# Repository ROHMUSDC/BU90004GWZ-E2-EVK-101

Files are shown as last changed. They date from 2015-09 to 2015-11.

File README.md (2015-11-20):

# BU90004GWZ-E2-EVK-101 Design Resource Repository
* Hardware Design Files and Documentation for the ROHM BU90004GWZ-E2-EVK-101 EVK

----
### Description: 
* BU90004GWZ is a high efficiency 6MHz synchronous step-down switching regulator with ultra low current PFM mode.
* This DCDC Converter can provide up to 1.0A load current from an input voltage range between 3.0V to 5.5V
* optimized for battery powered portable applications
* Includes a mode control pin that allows the user to select between Forced PWM(Pulse Width Modulation) mode, PFM(Pulse Frequency Modulation) mode, or PWM/PFM Auto Change mode utilized power save operation at light load current

----
### Repository Contents
* Application Note Folder: Contains Draft Version of EVK Application Note
* Design Files: Contains Board, Gerber, Schematic, and BOM information for this EVK Board
* Measurement Reports Folder: Contains measurement testing information completed for these EVK Boards

----
### Where to Purchase?
* http://www.rohm.com/web/global/distribution/-/dinventory/BU90004GWZ-E2/sample/0

----
### DISCLAIMER
This Technical Data is protected under copyright laws.

ROHM hereby grants you a nonexclusive, nontransferable license to use this Technical Data 
as long as you abide by the terms and conditions of this DISCLAIMER. 

However, you are not authorized to sell, loan, rent, lease, redistribute or license this Technical Data, 
in whole or in part, or in modified form, to anyone.

You may modify this Technical Data to suit your specific applications, 
but the rights to derivative works and said modifications shall belong to ROHM. 

You may make copies of this Technical Data as necessary for internal use only within your company.

In any case, the latest datasheet is considered the final design guideline and represents 
the only actual performance specifications.

ROHM shall not be responsible for ensuring proper application on all computer systems.
This Technical Data is provided AS IS. ROHM makes no guarantees, either implicitly or explicitly, 
regarding its usability, functionality, accuracy, merchantability, or fitness for a specific purpose.

In addition, you shall take full responsibility for the use of any information acquired from this Technical Data. 

ROHM does not assume warranty of any kind arising from the use of this Technical Data. ACCORDINGLY, 
IN NO EVENT SHALL ROHM BE RESPONSIBLE, WHETHER THROUGH CONTRACT OR TORT LIABILITY, 
FOR ANY DAMAGES (INCLUDING BUT NOT LIMITED TO LOST PROFITS OR OTHER INCIDENTAL, CONSEQUENTAL, 
OR PUNITIVE DAMAGES) ARISING OUT OF OR IN CONNECTION WITH THE USE OR APPLICATION OF THIS Technical Data.

Furthermore, this Technical Data is subject to change without notice.

Unless otherwise expressly provided herein, ROHM does not convey any license under patent rights 
or any other intellectual property rights (including those of third parties).

ROHM is not obligated to provide maintenance or support for the Technical Data.

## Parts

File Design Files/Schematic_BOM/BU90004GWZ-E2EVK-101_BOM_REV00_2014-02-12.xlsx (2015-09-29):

TITLE & REVISION HISTORY Revised: Wednesday, February 12, 2014
xxxxx Revision: 00
Bill Of Materials February 12,2014 14:28:24 | Page1
Item | Quantity | Reference | Part | PCB Footprint | DESCRIPTION | MFG1 | MFG1_PART# | DISTR1 | DISTR1_PART# | Provided by ROHM | ROHM Comment
1 | 2 | C1,C2 | 4.7uF | C0603 | CAP CER 4.7UF 6.3V 10% X5R 0603 | Murata | GRM188R60J475KE19D | DIGIKEY | 490-3297-1-ND | Y
2 | 1 | C3 | 0.1uF | C0603 | CAP CER 0.1UF 25V 10% X7R 0603 | Murata | GRM188R71E104KA01D | DIGIKEY | 490-1524-1-ND | Y
3 | 1 | D1 | P4SMA6.8A | DO-214AC | DIODE TVS 400W 6.8V UNI 5% SMD | Littelfuse Inc | P4SMA6.8A | DIGIKEY | F5656CT-ND | N
4 | 2 | J1,J2 | 87224-3 | HDR_THVT_1X3_100 | CONN HEADER VERT .100 3POS 15AU | TE Connectivity | 87224-3 | DIGIKEY | A26545-ND | N
5 | 1 | L1 | 1.0uH | SMT_2P5X2P0_FIT | INDUCTOR POWER 1.0UH 2.3A SMD | TDK | MLP2520K1R0ST0S1 | DIGIKEY | 445-15739-1-ND | Y
6 | 2 | TP1,TP3 | TP_TH_63MIL_RED | TP_TH | TEST POINT PC MULTI PURPOSE RED | Keystone Electronics | 5010 | DIGIKEY | 5010K-ND | N
7 | 2 | TP2,TP4 | TP_TH_63MIL_BLK | TP_TH | TEST POINT PC MULTI PURPOSE BLK | Keystone Electronics | 5011 | DIGIKEY | 5011K-ND | N
8 | 1 | U1 | BU90004GWZ | UCSP35L1 | IC REG BUCK SYNC 1.8V 1A 6WLCSP | ROHM | BU90004GWZ-E2 | DIGIKEY | BU90004GWZ-E2TR-ND | Y
9 | 2 |  |  |  | Shunt jumper for header J1, J2 (item #4), CONN SHUNT 2POS GOLD W/HANDLE | TE Connectivity | 881545-1 | DIGIKEY | 881545-1-ND | N

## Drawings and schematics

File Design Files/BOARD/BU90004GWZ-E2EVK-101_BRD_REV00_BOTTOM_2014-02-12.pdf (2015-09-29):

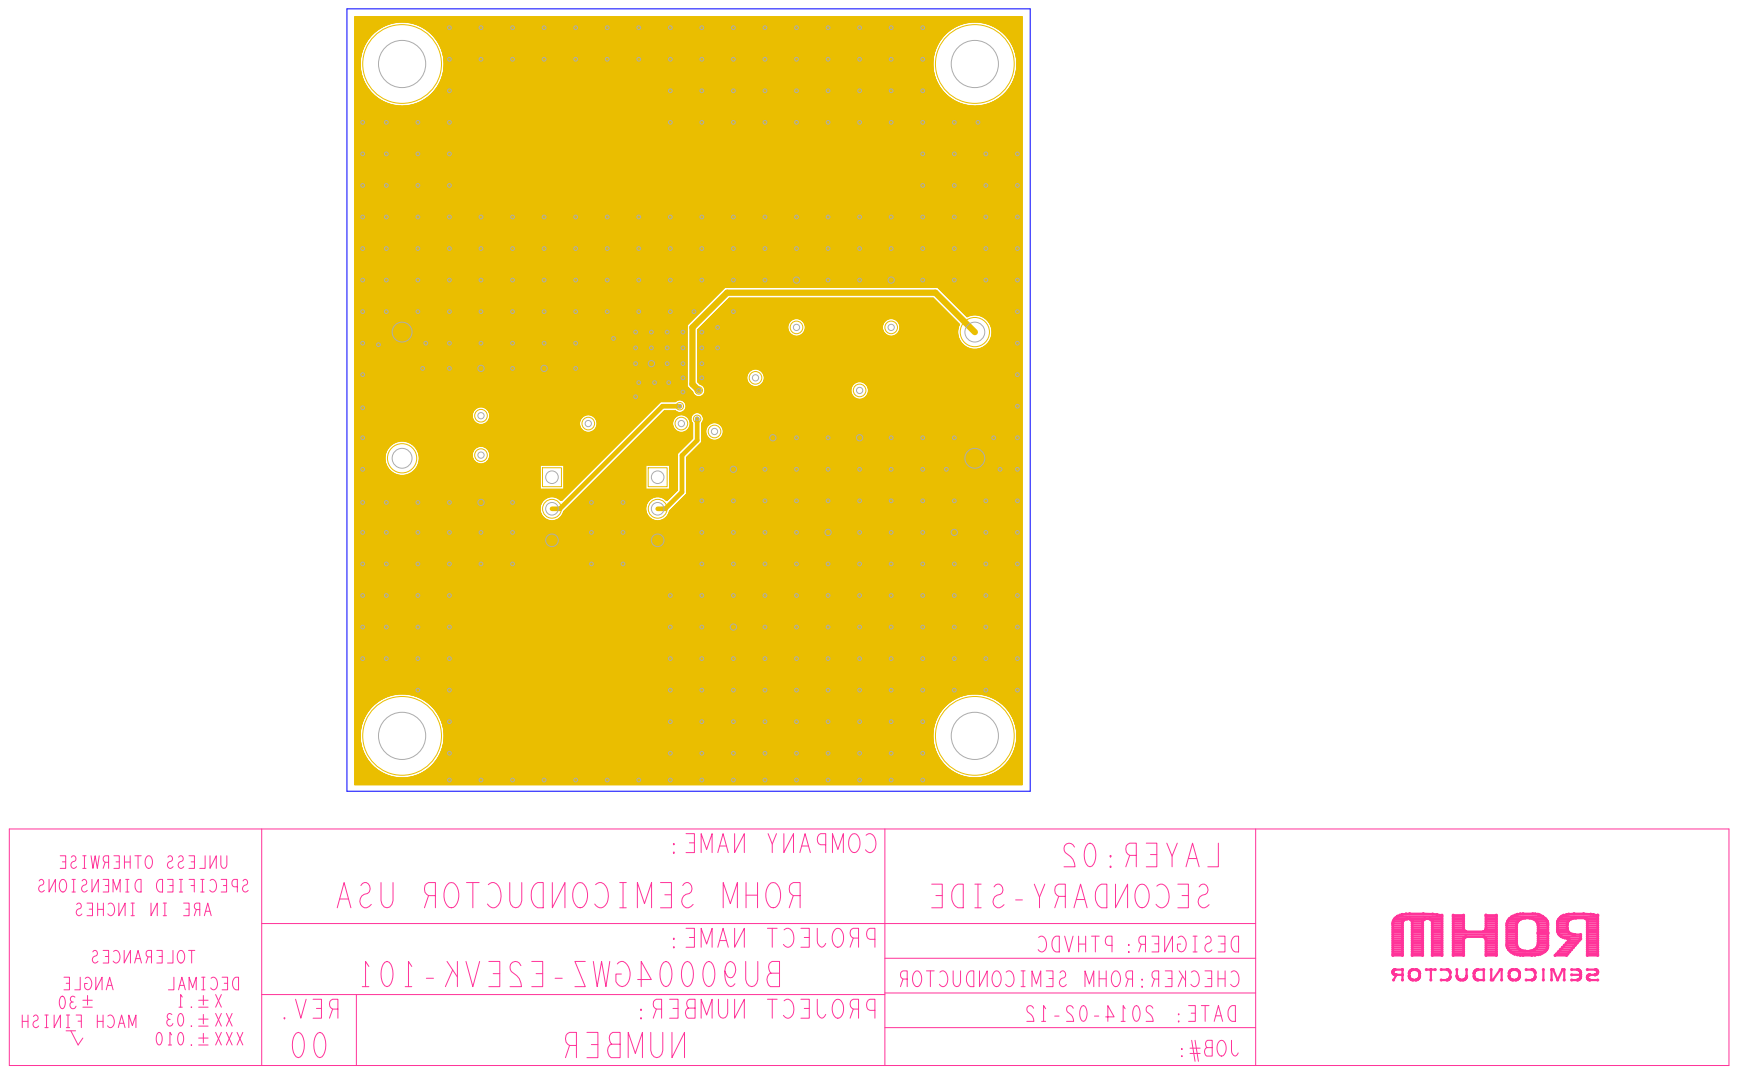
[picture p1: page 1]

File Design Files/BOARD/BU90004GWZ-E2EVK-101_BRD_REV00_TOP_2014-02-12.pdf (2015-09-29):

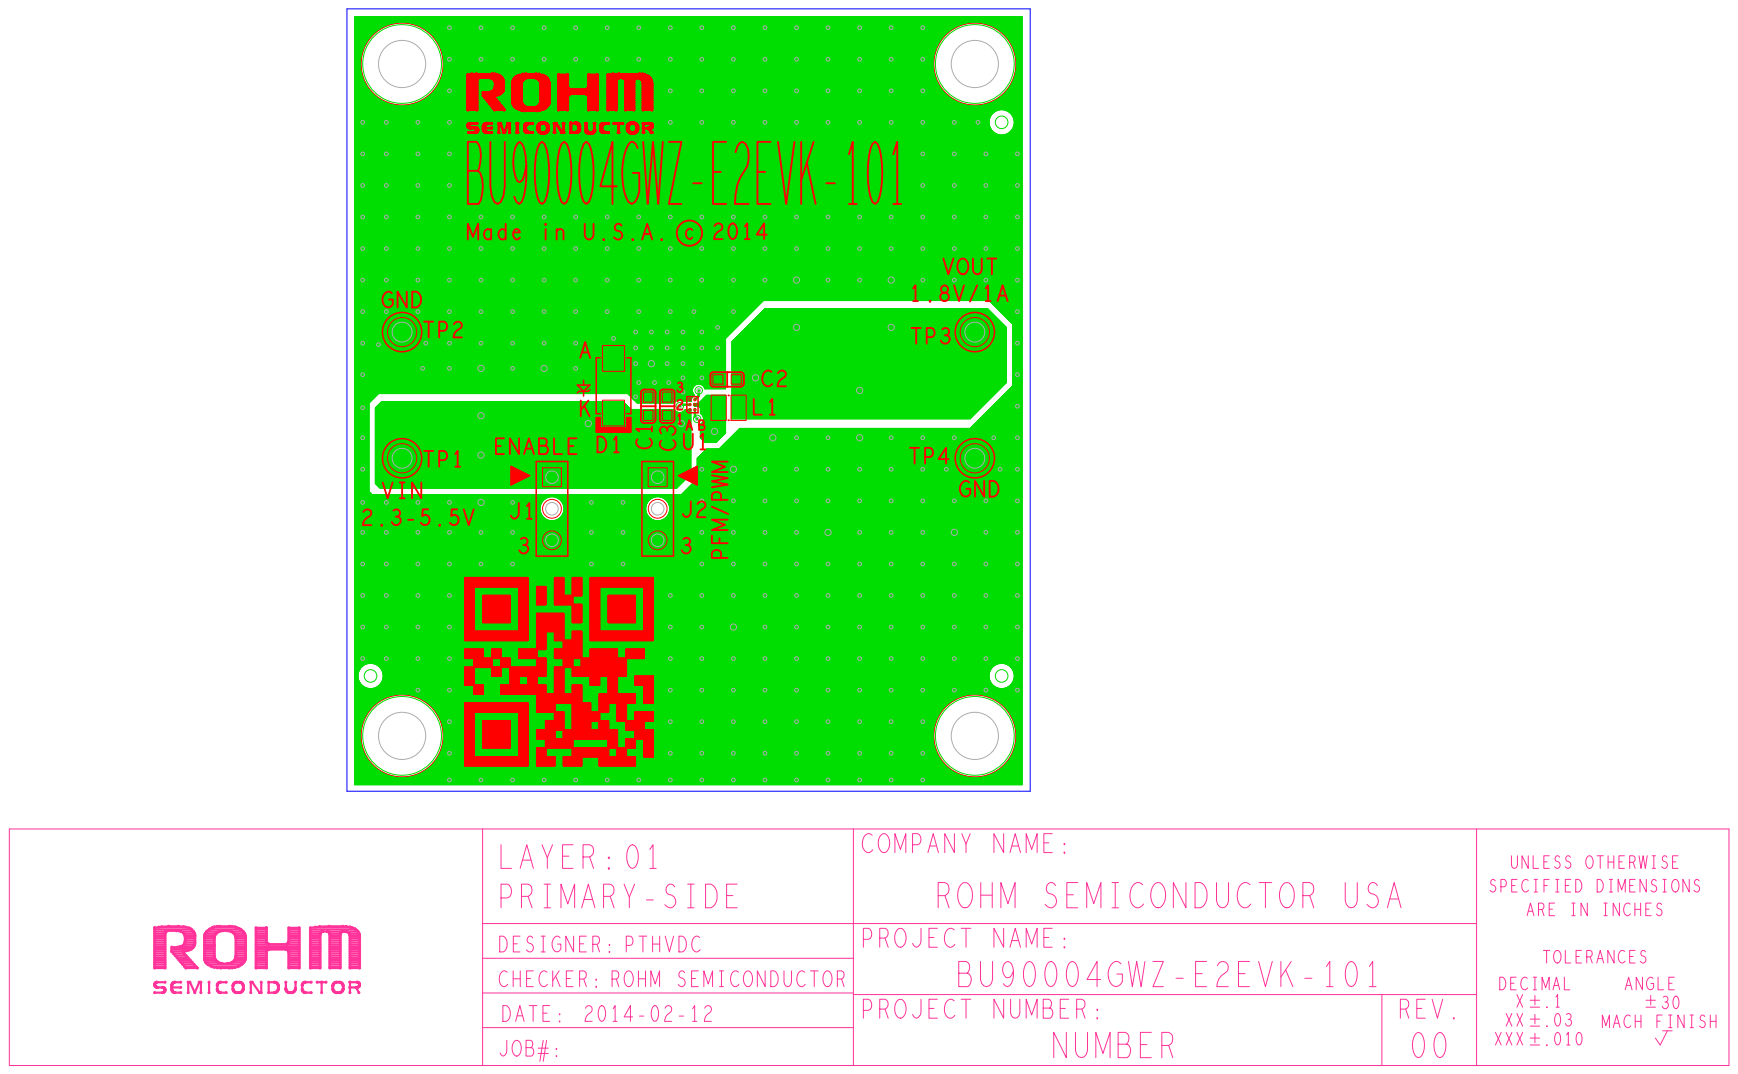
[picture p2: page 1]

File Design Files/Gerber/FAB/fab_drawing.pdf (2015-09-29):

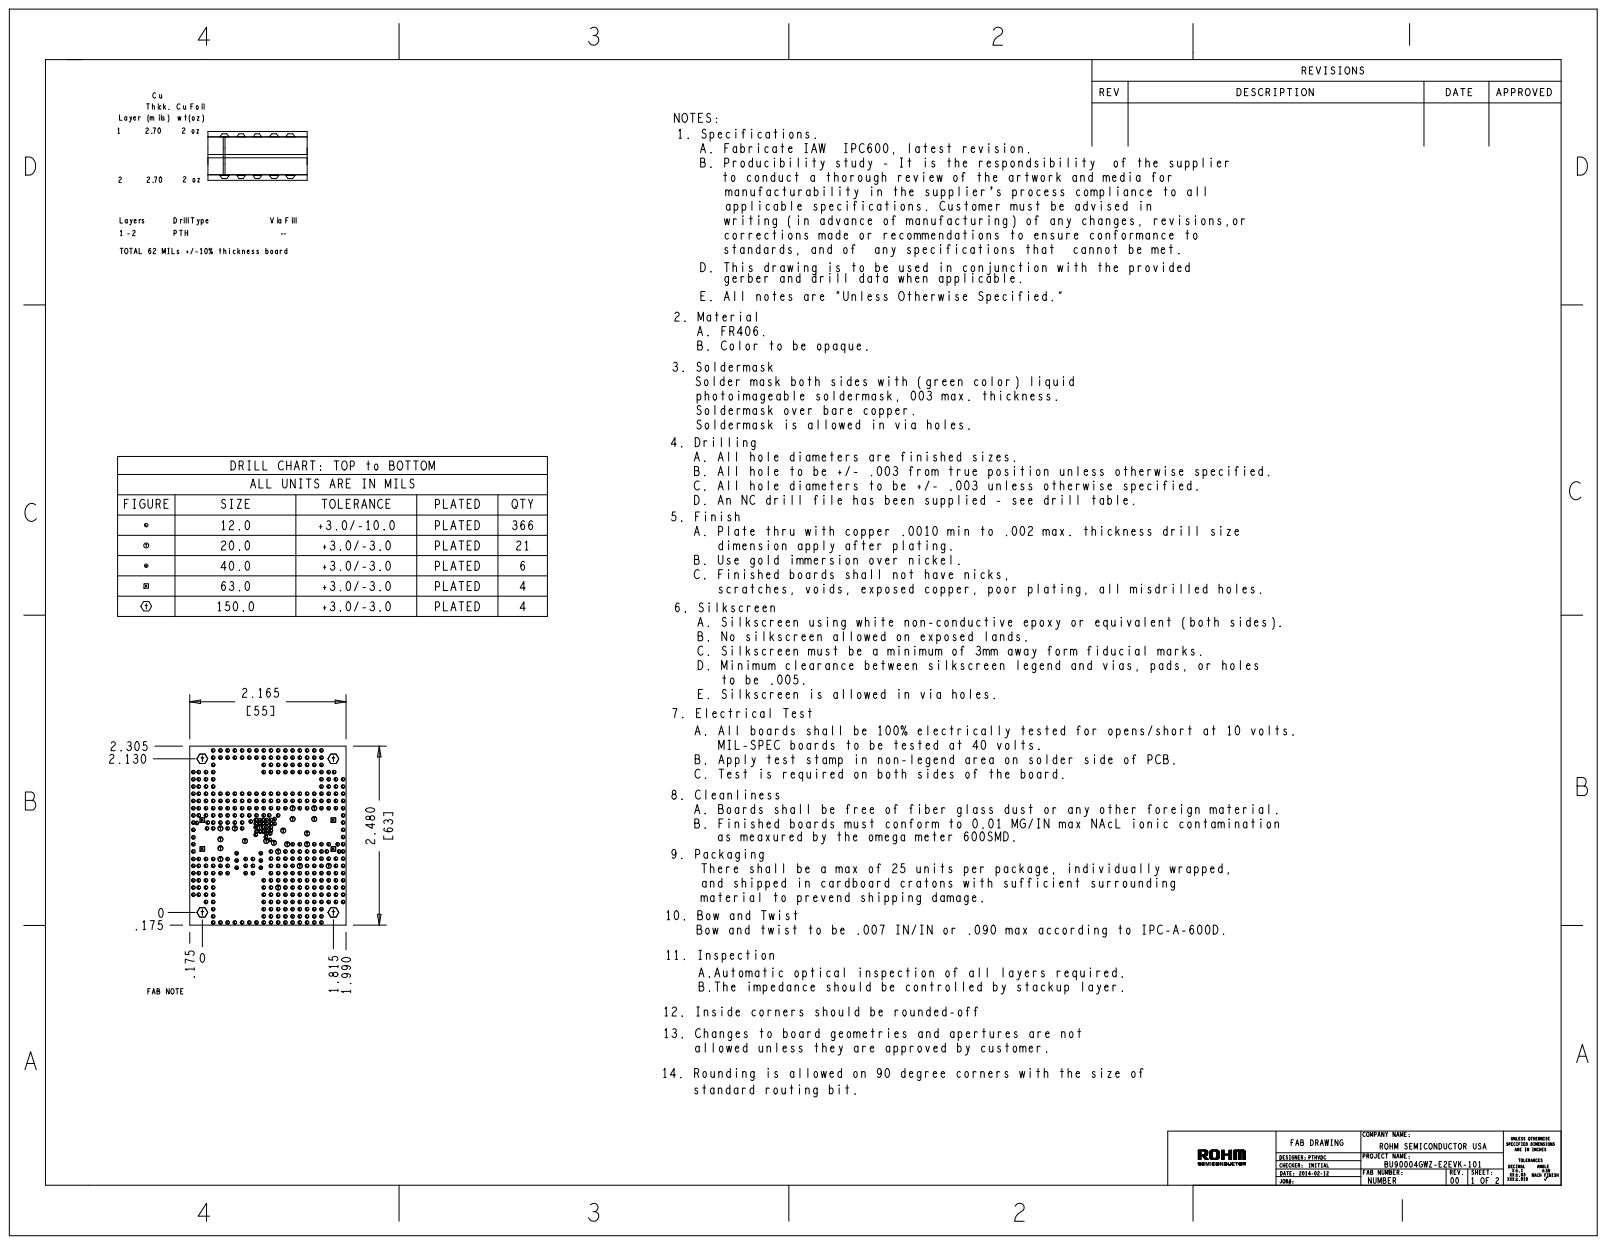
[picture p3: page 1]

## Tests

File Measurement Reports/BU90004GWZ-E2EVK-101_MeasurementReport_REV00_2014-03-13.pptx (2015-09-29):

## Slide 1

PTH Solutions Confidential

BU90004GWZ-E2EVK-101 Measurement Report
March 13th, 2014
Hosted by: Xuan Dang

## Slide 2

Equipment list

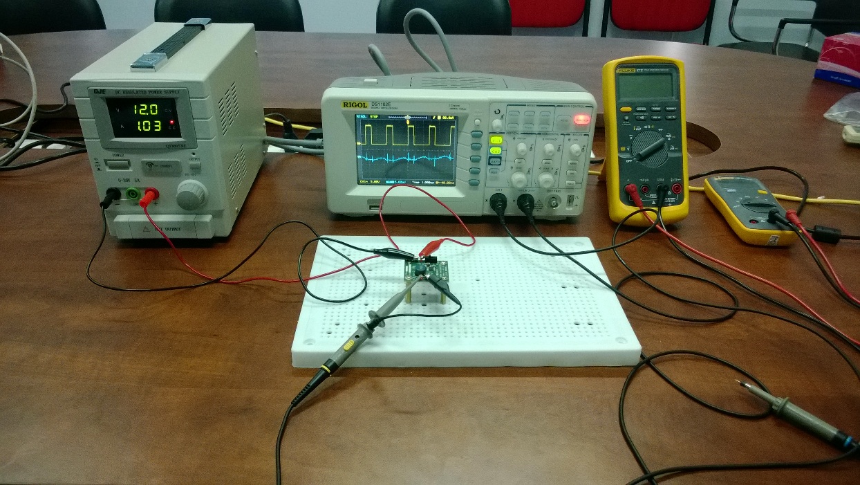
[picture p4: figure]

- Regulated DC Power Supply
  - QJE QJ3005XE (0-30V/5A)
- Multimeter:
  - Fluke 87V True RMS
  - Fluke 106
- Oscilloscope
  - Rigol DS1102E
- Electronic Load
  - B&K BK8500
- Current probe
  - RP1001C

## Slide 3

1. Functional Test

- Test case 1 procedure
  1. Connect DC Supply to: [+]VIN(TP1) and [-]GND(TP2) when EN is off. Set output of DC Supply in range from 2.3V to 5.5V and turn it on.
  2. Connect Electronic Load to: [+]VOUT(TP3) and [-]GND(TP4). Power on Electronic Load, set input of Electronic Load to 1A and turn on load.
  3. Move J1 header to turn EN on.
- Result:
VIN = 2.3V ~ 5.5V
IOUT = 1A
VOUT = 1.69V ~ 1.80V (in both modes, Automatic PFM/PWM and Automatic PFM/PWM). Test passed.

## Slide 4

1. Functional Test (cont.)

- Test case 2 procedure
  1. After implement test case 1, the IC operate properly.
  2. Move J1 header to turn EN off.
  3. Move J1 header to turn EN on.
- Result:
VIN = 5V.
VOUT = 0.21V/1A (in both modes, Automatic PFM/PWM and Automatic PFM/PWM). Test failed.

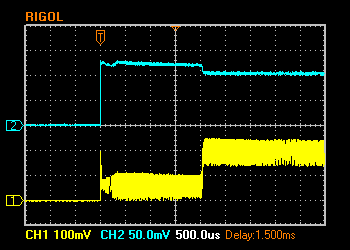
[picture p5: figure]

IOUT 0.5A/Div. (DC)

VOUT 100mV/Div. (DC)

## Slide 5

1. Functional Test (cont.)

- Test case 3 procedure
  1. After implement test case 1, the IC operate properly.
  2. Turn off DC Supply.
  3. Turn off load( don’t power off Electronic Load).
  4. Move J1 header to turn EN off.
  5. Turn on load.
  6. Turn on DC Supply.
  7. Move J1 header to turn EN on.
- Result:
VIN = 5V.
VOUT = 0.21V/1A (in both modes, Automatic PFM/PWM and Automatic PFM/PWM). Test failed.

IOUT 0.5A/Div. (DC)

VOUT 100mV/Div. (DC)

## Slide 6

1. Functional Test (cont.)

- Test case 4 procedure
  1. Connect DC Supply to: [+]VIN(TP1) and [-]GND(TP2) when EN is off. Set output of DC Supply in range from 2.3V to 5.5V and turn it on.
  2. Connect Electronic Load to: [+]VOUT(TP3) and [-]GND(TP4). Set input of Electronic Load to 1A and don’t turn on load.
  3. Move J1 header to turn EN on when load is still off.
  4. Turn on load.
- Result:
VIN = 2.3V ~ 5.5V
IOUT = 1A
VOUT = 1.69V ~ 1.80V (in both modes, Automatic PFM/PWM and Automatic PFM/PWM). Test passed.

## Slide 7

1. Functional Test (cont.)

- Test case 5 procedure
  1. After implement test case 1, the IC operate properly.
  2. Turn off load.
  3. Turn on load.
- Result:
VIN = 2.3V ~ 5.5V
IOUT = 1A
VOUT = 1.69V ~ 1.80V (in both modes, Automatic PFM/PWM and Automatic PFM/PWM). Test passed.

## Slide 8

2. Hot Plugging Test

- Test condition
  - VIN = 5.5V
  - IOUT = 1A
  - With original diode D1: P4SMA6.8A
- Result:
- IIN_PEAK= 15A
- VIN peak transient voltage (in both modes) is 7.68V > VIN Maximum Rating (7V)
- The IC still operate properly after 100+ testing time.

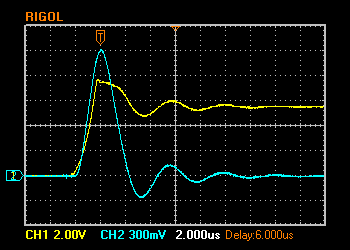
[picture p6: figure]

VIN 2V/Div. (DC)

IIN 3A/Div. (AC)

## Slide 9

3. Circuit Quiescent Current Measurement

- Test condition
  - VIN = 0-5.5V
  - Automatic PFM/PWM Mode
  - Room temperature 25oC

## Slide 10

3. Circuit Quiescent Current Measurement (cont.)

- Test condition
  - VIN = 0-5.5V
  - Forced PWM Mode
  - Room temperature 25oC

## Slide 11

4. Efficiency Measurements

- Test condition
  - VIN = 5V
  - VOUT = 1.8V
  - Room temperature 25oC

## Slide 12

5. Load Response Measurements

Load response characteristic
(VIN=5V, VOUT=1.8V, IOUT=0 → 1A, Automatic PFM/PWM Mode)

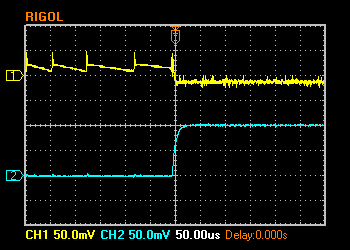
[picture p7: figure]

VOUT 50mV/Div. (AC)

IOUT 0.5A/Div. (DC)

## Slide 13

5. Load Response Measurements (cont.)

Load response characteristic
(VIN=5V, VOUT=1.8V, IOUT=1A → 0, Automatic PFM/PWM Mode)

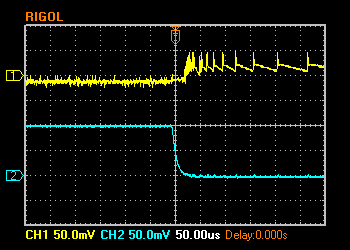
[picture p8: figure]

VOUT 50mV/Div. (AC)

IOUT 0.5A/Div. (DC)

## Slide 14

5. Load Response Measurements (cont.)

Load response characteristic
(VIN=5V, VOUT=1.8V, IOUT=0 → 1A, Forced PWM Mode)

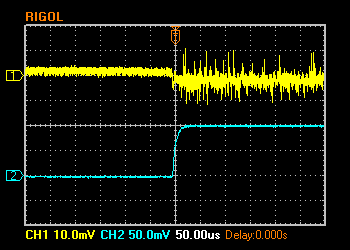
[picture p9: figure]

VOUT 10mV/Div. (AC)

IOUT 0.5A/Div. (DC)

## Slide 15

5. Load Response Measurements (cont.)

Load response characteristic
(VIN=5V, VOUT=1.8V, IOUT=1A → 0, Forced PWM Mode)

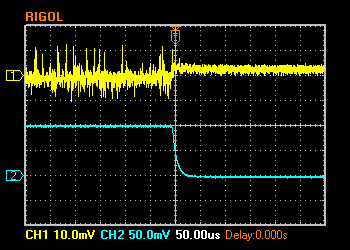
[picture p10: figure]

VOUT 10mV/Div. (AC)

IOUT 0.5A/Div. (DC)

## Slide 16

6. Ripple Response Measurements

VOUT Ripple voltage
(VIN=5V, VOUT=1.8V, IOUT=1A, Automatic PFM/PWM Mode and Forced PWM Mode)

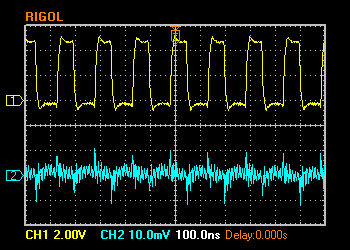
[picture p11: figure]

VSW 2V/Div. (DC)

VOUT 10mV/Div. (AC)

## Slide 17

6. Ripple Response Measurements (cont.)

VOUT Ripple voltage
(VIN=5V, VOUT=1.8V, IOUT=10mA, Automatic PFM/PWM Mode)

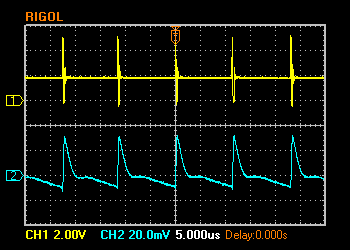
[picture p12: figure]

VSW 2V/Div. (DC)

VOUT 20mV/Div. (AC)

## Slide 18

6. Ripple Response Measurements (cont.)

VOUT Ripple voltage
(VIN=5V, VOUT=1.8V, IOUT=10mA, Forced PWM Mode)

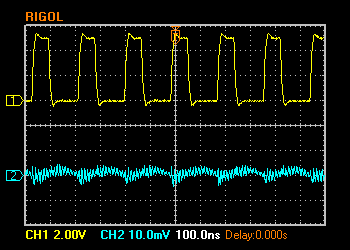
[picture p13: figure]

VSW 2V/Div. (DC)

VOUT 10mV/Div. (AC)

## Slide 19

7. Input Voltage Ripple Measurements

VIN Ripple voltage
(VIN=5V, VOUT=1.8V, CIN=4.7uF + 0.1uF, IOUT=0A, Automatic PFM/PWM Mode)


VIN 20mV/Div. (AC)

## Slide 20

7. Input Voltage Ripple Measurements (cont.)

VIN Ripple voltage
(VIN=5V, VOUT=1.8V, CIN=4.7uF + 0.1uF, IOUT=1A, Automatic PFM/PWM Mode)


VIN 50mV/Div. (AC)

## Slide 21

7. Input Voltage Ripple Measurements (cont.)

VIN Ripple voltage
(VIN=5V, VOUT=1.8V, CIN=4.7uF + 0.1uF, IOUT=0A, Forced PWM Mode)


VIN 10mV/Div. (AC)

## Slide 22

7. Input Voltage Ripple Measurements (cont.)

VIN Ripple voltage
(VIN=5V, VOUT=1.8V, CIN=4.7uF + 0.1uF, IOUT=1A, Forced PWM Mode)


VIN 50mV/Div. (AC)

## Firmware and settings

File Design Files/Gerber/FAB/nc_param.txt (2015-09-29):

INTEGER-PLACES         2
DECIMAL-PLACES         4
X-OFFSET               0.000000
Y-OFFSET               0.000000
FEEDRATE               1
COORDINATES            ABSOLUTE
OUTPUT-UNITS           ENGLISH
TOOL-ORDER             INCREASING
REPEAT-CODES           YES
SUPPRESS-LEAD-ZEROES   NO
SUPPRESS-TRAIL-ZEROES  NO
SUPPRESS-EQUAL         NO
TOOL-SELECT            NO
OPTIMIZE_DRILLING      NO
ENHANCED_EXCELLON      NO
HEADER                 none
LEADER                 12
CODE                   ASCII
SEPARATE               NO
DRILLING               LAYER-PAIR
BACKDRILL              NO
